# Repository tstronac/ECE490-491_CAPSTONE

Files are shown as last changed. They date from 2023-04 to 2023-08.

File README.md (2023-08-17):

# ECE490-491_CAPSTONE
Capstone project for my EE degree 
Designed and built an IoT Ultraviolet (UV) fire sensing device to identify and extinguish wildfire entering a community, using LoRaWAN protocol 
Designed both the sensor units  (a Sprinkler unit and a UV sensor unit), designed a UV wave guide to increase range of sensor.
We used a RAK3272s for the LoRa Communication, and an STM32 board for the control side of things. 

The sensor board has a solar charger circuitry available, I used the design from the sunnybuddy by sparkfun (under a Beerware license 🍻), and made some adjustments as neccesary.

You can find the schematics below and pics of it working.
Enjoy!!!

(Note: V3 is current)

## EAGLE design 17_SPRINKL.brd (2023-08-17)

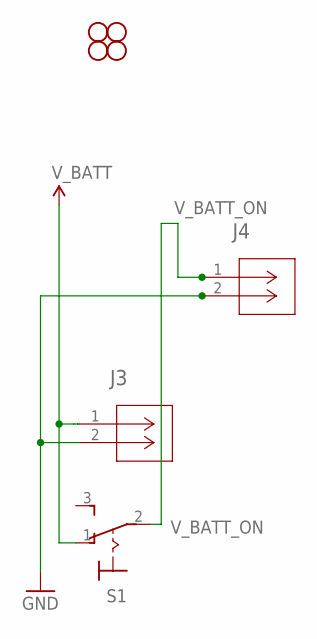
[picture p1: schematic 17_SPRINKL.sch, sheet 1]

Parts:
J3, J4: 1729128; CONN_1729128_PXC
S1: M9040P
STANDOFF1, STANDOFF2, STANDOFF3, STANDOFF4: STAND-OFF

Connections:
GND: J3.2, J4.2; also elsewhere on the board
V_BATT: J3.1, S1.1 (O)
V_BATT_ON: J4.1, S1.2; also elsewhere on the board

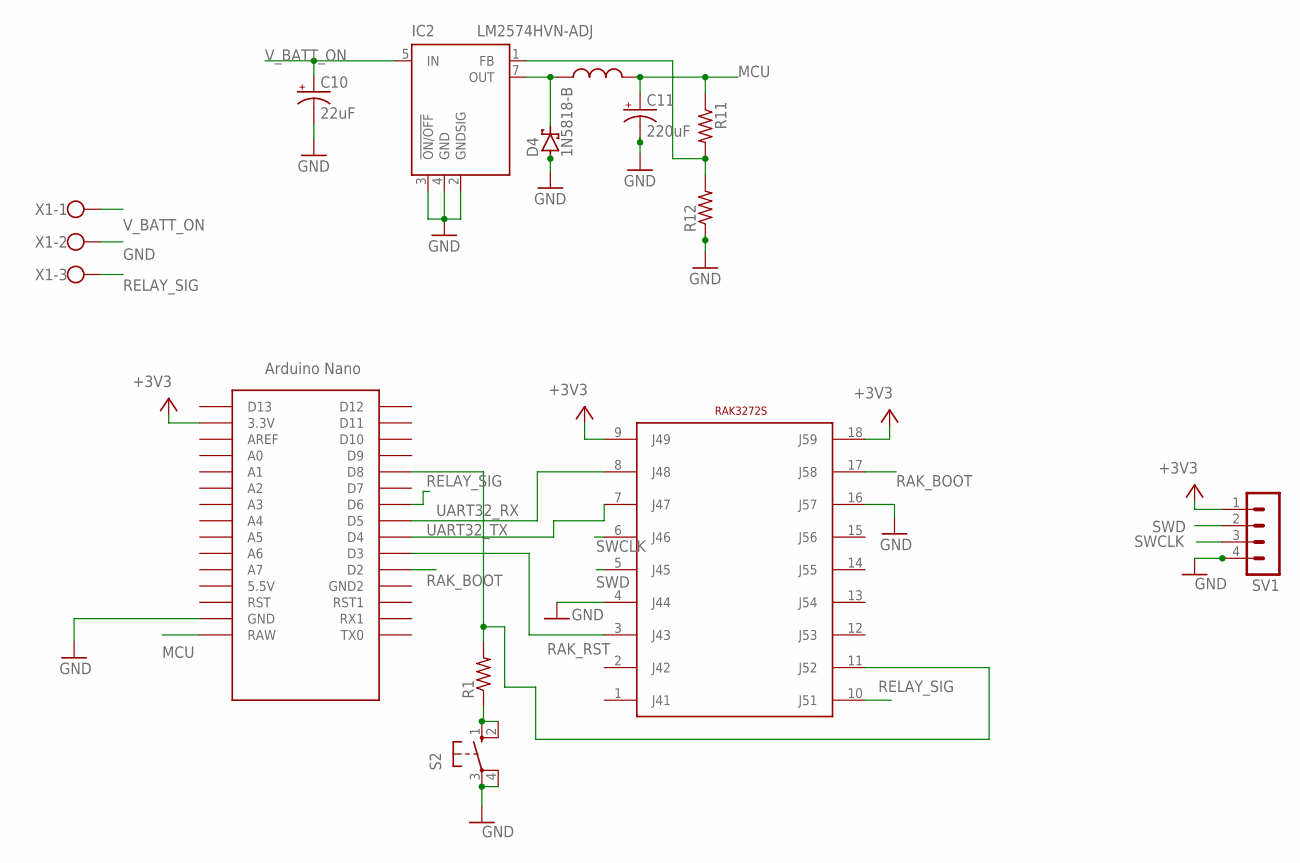
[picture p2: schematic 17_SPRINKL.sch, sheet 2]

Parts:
C10: 22uF; E5-6
C11: 220uF; E5-6
D4: 1N5818-B; DO41-7.6
IC2: LM2574HVN-ADJ; DIL08
R1, R11, R12: R-US_0204/7; 0204/7
S2: 10-XX; B3F-10XX
SV1: MA04-1
U$1: 330UH_INDUCTOR
U$3: NANO
U$4: RAK3272S; RAK3272SFOOTPRINT
X1: W237-103

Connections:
+3V3: SV1.1, U$3.3.3V, U$4.9 (J49), U$4.18 (J59)
GND: C10.-, C11.-, D4.A, IC2.2 (GNDSIG), IC2.3 (!ON/OFF), IC2.4 (GND), R12.1, S2.3, S2.4 (P1), SV1.4, U$3.GND, U$4.4 (J44), U$4.16 (J57), X1.2; also elsewhere on the board
MCU: C11.+, R11.1, U$1.P$2, U$3.RAW
unnamed: D4.C, IC2.7 (OUT), U$1.P$1
unnamed: R1.1, S2.1 (S), S2.2 (S1)
unnamed: IC2.1 (FB), R11.2, R12.2
unnamed: R1.2, U$3.D8, U$4.11 (J52)
RAK_BOOT: U$3.D2, U$4.17 (J58)
RAK_RST: U$3.D3, U$4.3 (J43)
RELAY_SIG: U$3.D6, U$4.10 (J51), X1.3
SWCLK: SV1.3, U$4.6 (J46)
SWD: SV1.2, U$4.5 (J45)
UART32_RX: U$3.D4, U$4.7 (J47)
UART32_TX: U$3.D5, U$4.8 (J48)
V_BATT_ON: C10.+, IC2.5 (IN), X1.1; also elsewhere on the board

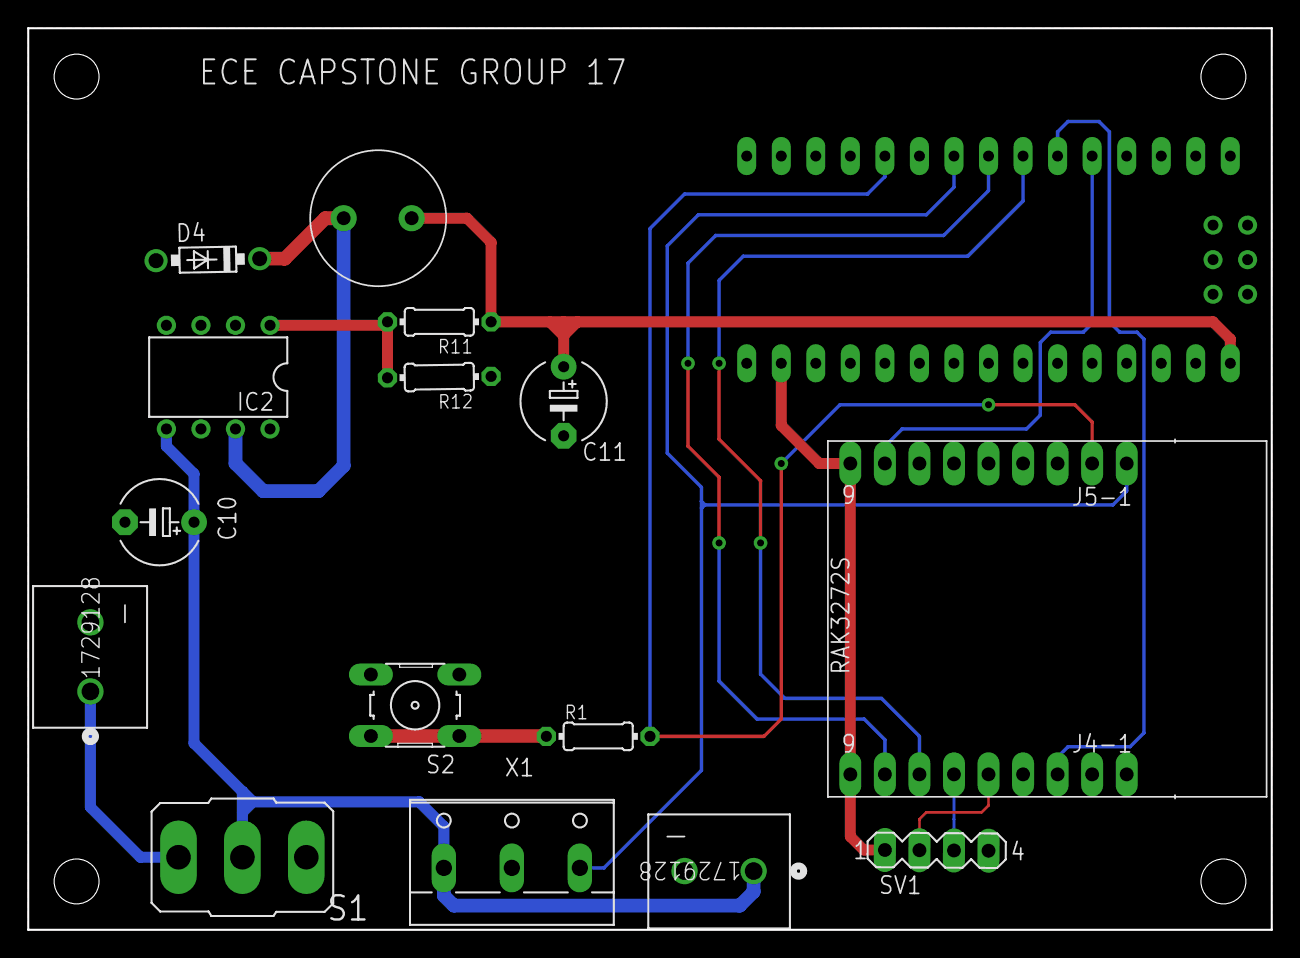
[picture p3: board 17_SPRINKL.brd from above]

Board: 2 copper layers, 91.4 x 66.3 mm, 20 parts (0 on the bottom side), 16 nets.

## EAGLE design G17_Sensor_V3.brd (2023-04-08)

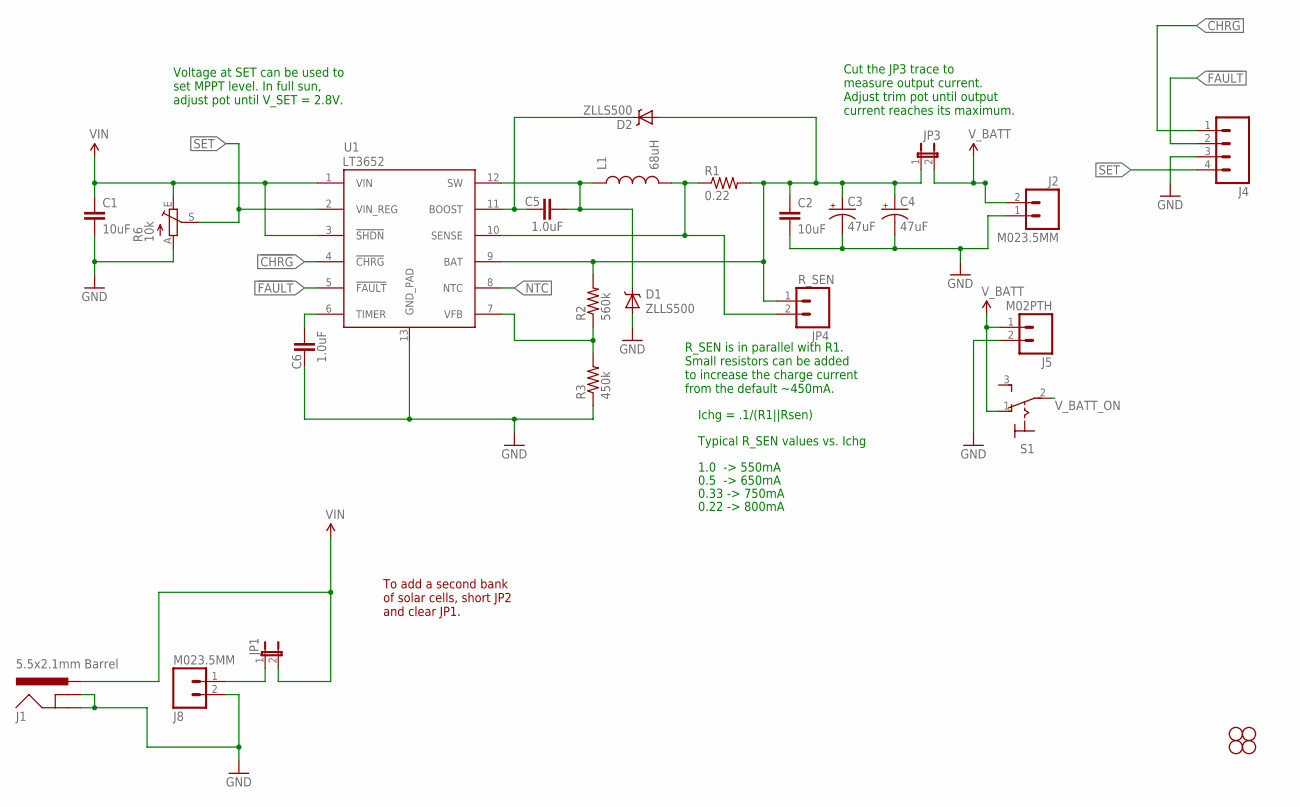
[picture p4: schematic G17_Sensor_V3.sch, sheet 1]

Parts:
C1: 10uF; 1210
C2: 10uF; 1206
C3, C4: 47uF; EIA3528
C5, C6: 1.0uF; 0603-CAP
D1, D2: ZLLS500; SOT23
J1: 5.5x2.1mm Barrel; POWER_JACK_SMD
J2, J8: M023.5MM; SCREWTERMINAL-3.5MM-2
J4: M04PTH; 1X04
J5: M02PTH; 1X02
JP1: JUMPER-2SMD-NC; SJ_2S
JP3: JUMPER-PTH-2-NC; PTH-JUMPER-NC_BOTTOM_NO_SILK
JP4: R_SEN; 1X02
L1: 68uH; CR75
R1: 0.22; 0805
R2: 560k; 0603-RES
R3: 450k; 0603-RES
R6: 10k; S63S
S1: M9040P
STANDOFF1, STANDOFF2, STANDOFF3, STANDOFF4: STAND-OFF
U1: LT3652; MSOP-12_GND

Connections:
!CHRG: J4.1, U1.4 (!CHRG)
!FAULT: J4.2, U1.5 (!FAULT)
BOOST: C5.1, D2.3 (C), U1.11 (BOOST)
FB: R2.1, R3.2, U1.7 (VFB)
GND: C1.2, C2.2, C3.C (-), C4.C (-), C6.1, D1.1 (A), J1.GND (GNDBREAK), J1.P$4 (GND), J2.1, J4.3, J5.2, J8.2, R3.1, R6.A, U1.13 (GND_PAD); also elsewhere on the board
unnamed: C2.1, C3.A (+), C4.A (+), D2.1 (A), JP3.1, JP4.1, R1.2, R2.2, U1.9 (BAT)
unnamed: J8.1, JP1.1
NTC: U1.8 (NTC)
SENSE: JP4.2, L1.P$2 (2), R1.1, U1.10 (SENSE)
SET: J4.4, R6.S, U1.2 (VIN_REG)
SW: C5.2, D1.3 (C), L1.P$1 (1), U1.12 (SW)
TIMER: C6.2, U1.6 (TIMER)
VIN: C1.1, J1.VIN0 (PWR), JP1.2, R6.E, U1.1 (VIN), U1.3 (!SHDN)
V_BATT: J2.2, J5.1, JP3.2, S1.1 (O)
V_BATT_ON: S1.2; also elsewhere on the board

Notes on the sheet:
To add a second bank of solar cells, short JP2 and clear JP1.
Cut the JP3 trace to measure output current. Adjust trim pot until output current reaches its maximum.
R_SEN is in parallel with R1. Small resistors can be added to increase the charge current from the default ~450mA.
0.22 -> 800mA
Ichg = .1/(R1||Rsen)
Typical R_SEN values vs. Ichg
1.0 -> 550mA
0.33 -> 750mA
0.5 -> 650mA
Voltage at SET can be used to set MPPT level. In full sun, adjust pot until V_SET = 2.8V.

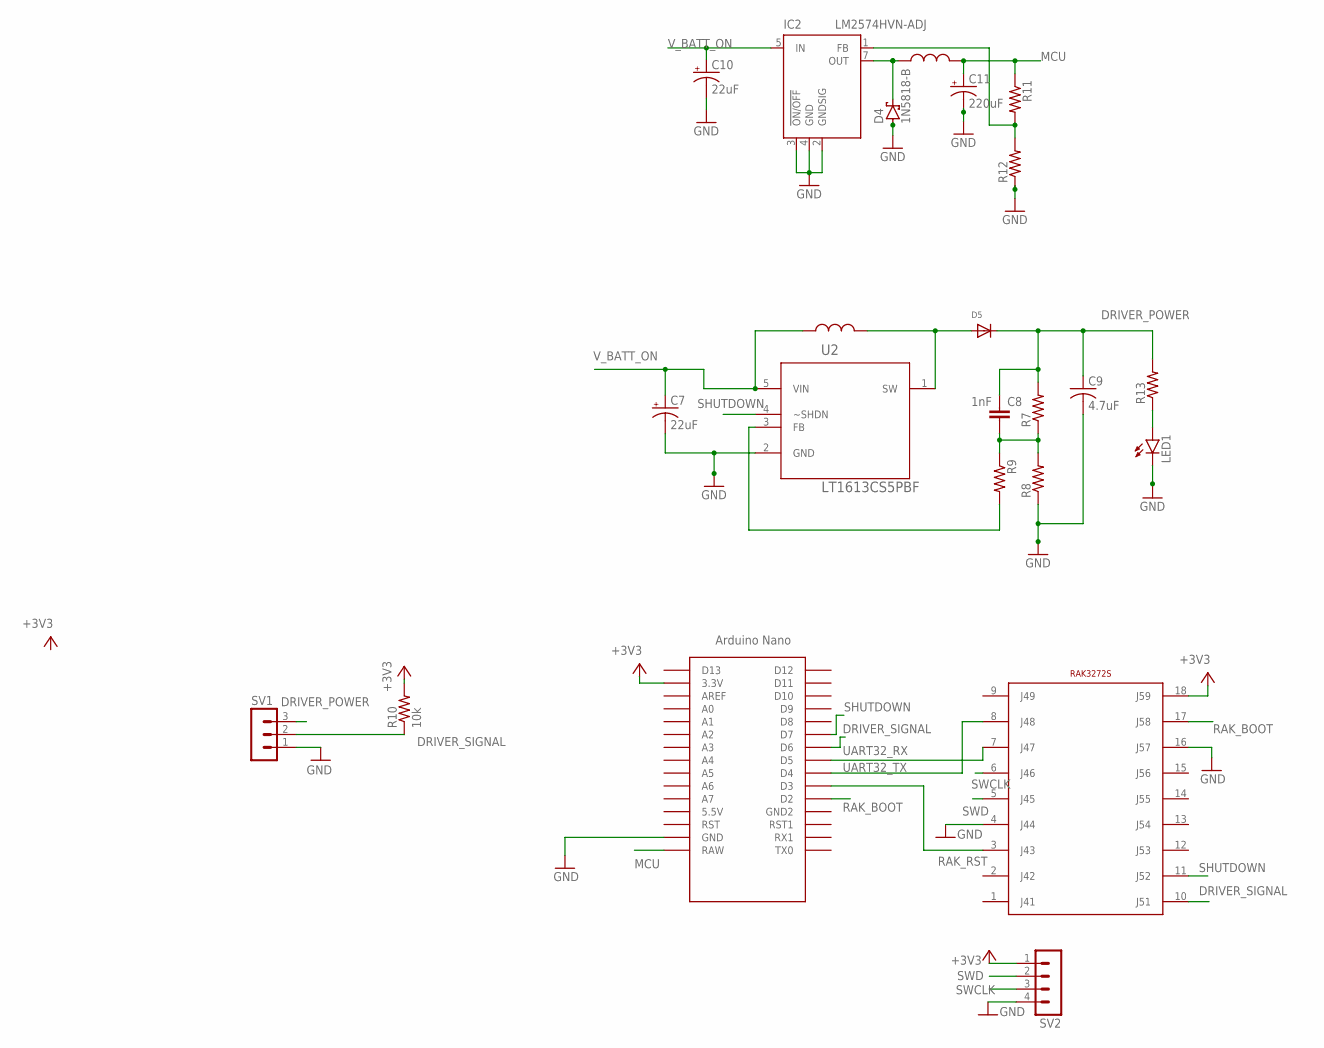
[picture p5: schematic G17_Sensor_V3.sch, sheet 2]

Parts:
C7, C10: 22uF; E5-6
C8: 1nF; C5B2.5
C9: 4.7uF; C025-024X044
C11: 220uF; E5-6
D4: 1N5818-B; DO41-7.6
D5: DIODESOD-123; SOD-123
IC2: LM2574HVN-ADJ; DIL08
LED1: LED5MM
R7, R8, R9, R13: R-US_0204/5; 0204/5
R10: 10k; 0204/5
R11, R12: R-US_0204/7; 0204/7
SV1: MA03-1
SV2: MA04-1
U2: LT1613CS5PBF; SOT95P280X145-5N
U$1, U$2: 330UH_INDUCTOR
U$3: NANO
U$4: RAK3272S; RAK3272SFOOTPRINT

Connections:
+3V3: R10.2, SV2.1, U$3.3.3V, U$4.18 (J59)
DRIVER_POWER: C8.1, C9.1, D5.C, R7.2, R13.2, SV1.3
DRIVER_SIGNAL: R10.1, SV1.2, U$3.D6, U$4.10 (J51)
GND: C7.-, C9.2, C10.-, C11.-, D4.A, IC2.2 (GNDSIG), IC2.3 (!ON/OFF), IC2.4 (GND), LED1.K (C), R8.1, R12.1, SV1.1, SV2.4, U2.2 (GND), U$3.GND, U$4.4 (J44), U$4.16 (J57); also elsewhere on the board
MCU: C11.+, R11.1, U$1.P$2, U$3.RAW
unnamed: IC2.1 (FB), R11.2, R12.2
unnamed: R9.2, U2.3 (FB)
unnamed: D5.A, U2.1 (SW), U$2.P$2
unnamed: D4.C, IC2.7 (OUT), U$1.P$1
unnamed: C8.2, R7.1, R8.2, R9.1
unnamed: LED1.A, R13.1
RAK_BOOT: U$3.D2, U$4.17 (J58)
RAK_RST: U$3.D3, U$4.3 (J43)
SHUTDOWN: U2.4 (~SHDN), U$3.D7, U$4.11 (J52)
SWCLK: SV2.3, U$4.6 (J46)
SWD: SV2.2, U$4.5 (J45)
UART32_RX: U$3.D5, U$4.7 (J47)
UART32_TX: U$3.D4, U$4.8 (J48)
V_BATT_ON: C7.+, C10.+, IC2.5 (IN), U2.5 (VIN), U$2.P$1; also elsewhere on the board

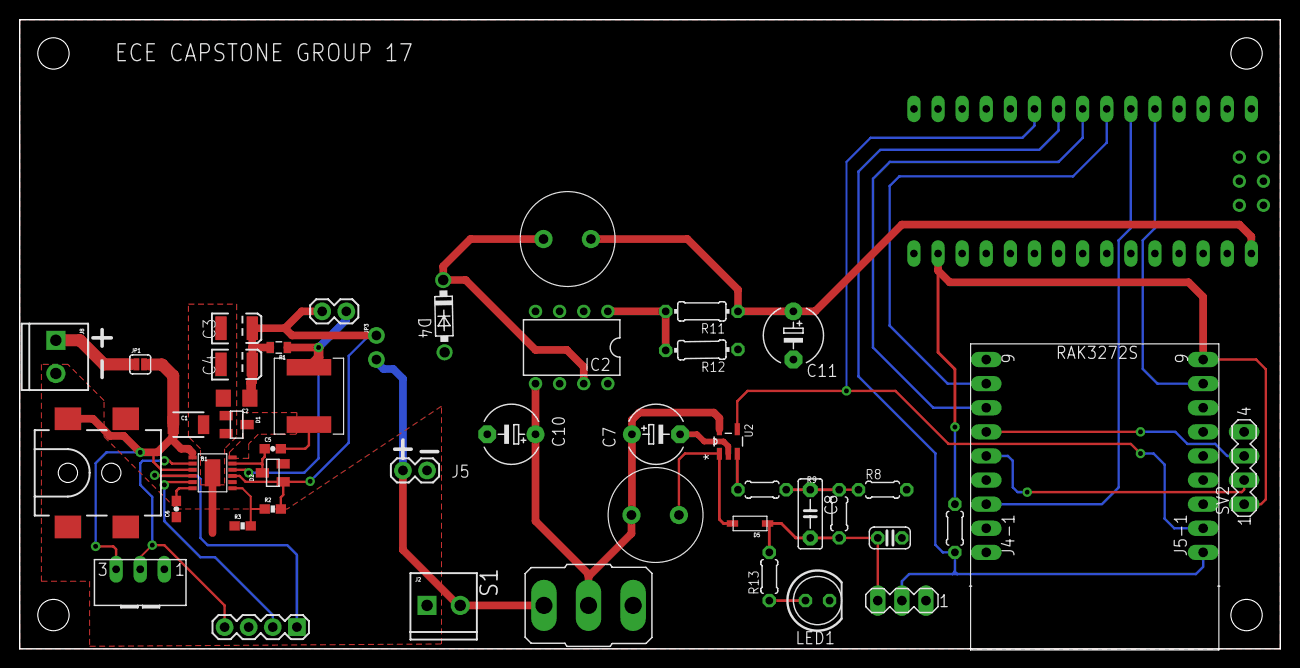
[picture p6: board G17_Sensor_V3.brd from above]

Board: 2 copper layers, 132.8 x 66.3 mm, 50 parts (0 on the bottom side), 31 nets.

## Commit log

2023-02-21 Add files via upload
    ThEGoOdsTuFf
    [Solar_Charger.brd, Solar_Charger.sch, SunnyBuddy.brd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]
2023-08-17 Sprinkler Board stuff
    Credit to Serena Nguyen-Vu and Timothy Stronach
    [17_SPRINKL.brd, 17_SPRINKL.sch]

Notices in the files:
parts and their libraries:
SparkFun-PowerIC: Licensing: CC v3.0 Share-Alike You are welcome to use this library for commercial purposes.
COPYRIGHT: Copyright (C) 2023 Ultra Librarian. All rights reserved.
